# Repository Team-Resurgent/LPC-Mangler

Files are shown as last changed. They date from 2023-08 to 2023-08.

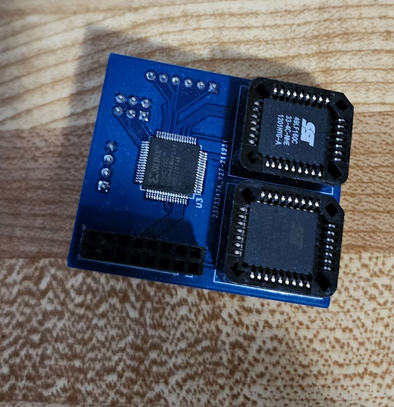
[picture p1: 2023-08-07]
Mangler2.png

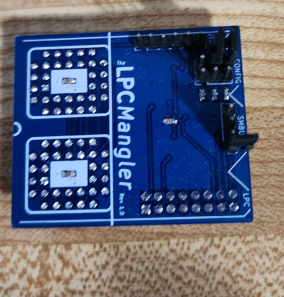
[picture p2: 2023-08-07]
Mangler1.png

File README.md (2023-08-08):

# LPC Mangler
 
A WIP/Concept Mod for original xbox. Designed by Members from Team Resurgent.
It intercepts the LPC commands between the chipset and an LPC flash chip, rewriting the command and address bits so you can use larger, later chips that don't normally reside at the same addresses as typical LPC flash chips used in simpler mods like the Aladdin , and does so while adding as few extra clock cycles as possible to the transaction

Would love for the community to contribute & complete the design

Currently supports upto 4MB Flashes. Also has ability for serial output etc.

Requires Lframe to be implemented to work with higher rev xbox possibly.

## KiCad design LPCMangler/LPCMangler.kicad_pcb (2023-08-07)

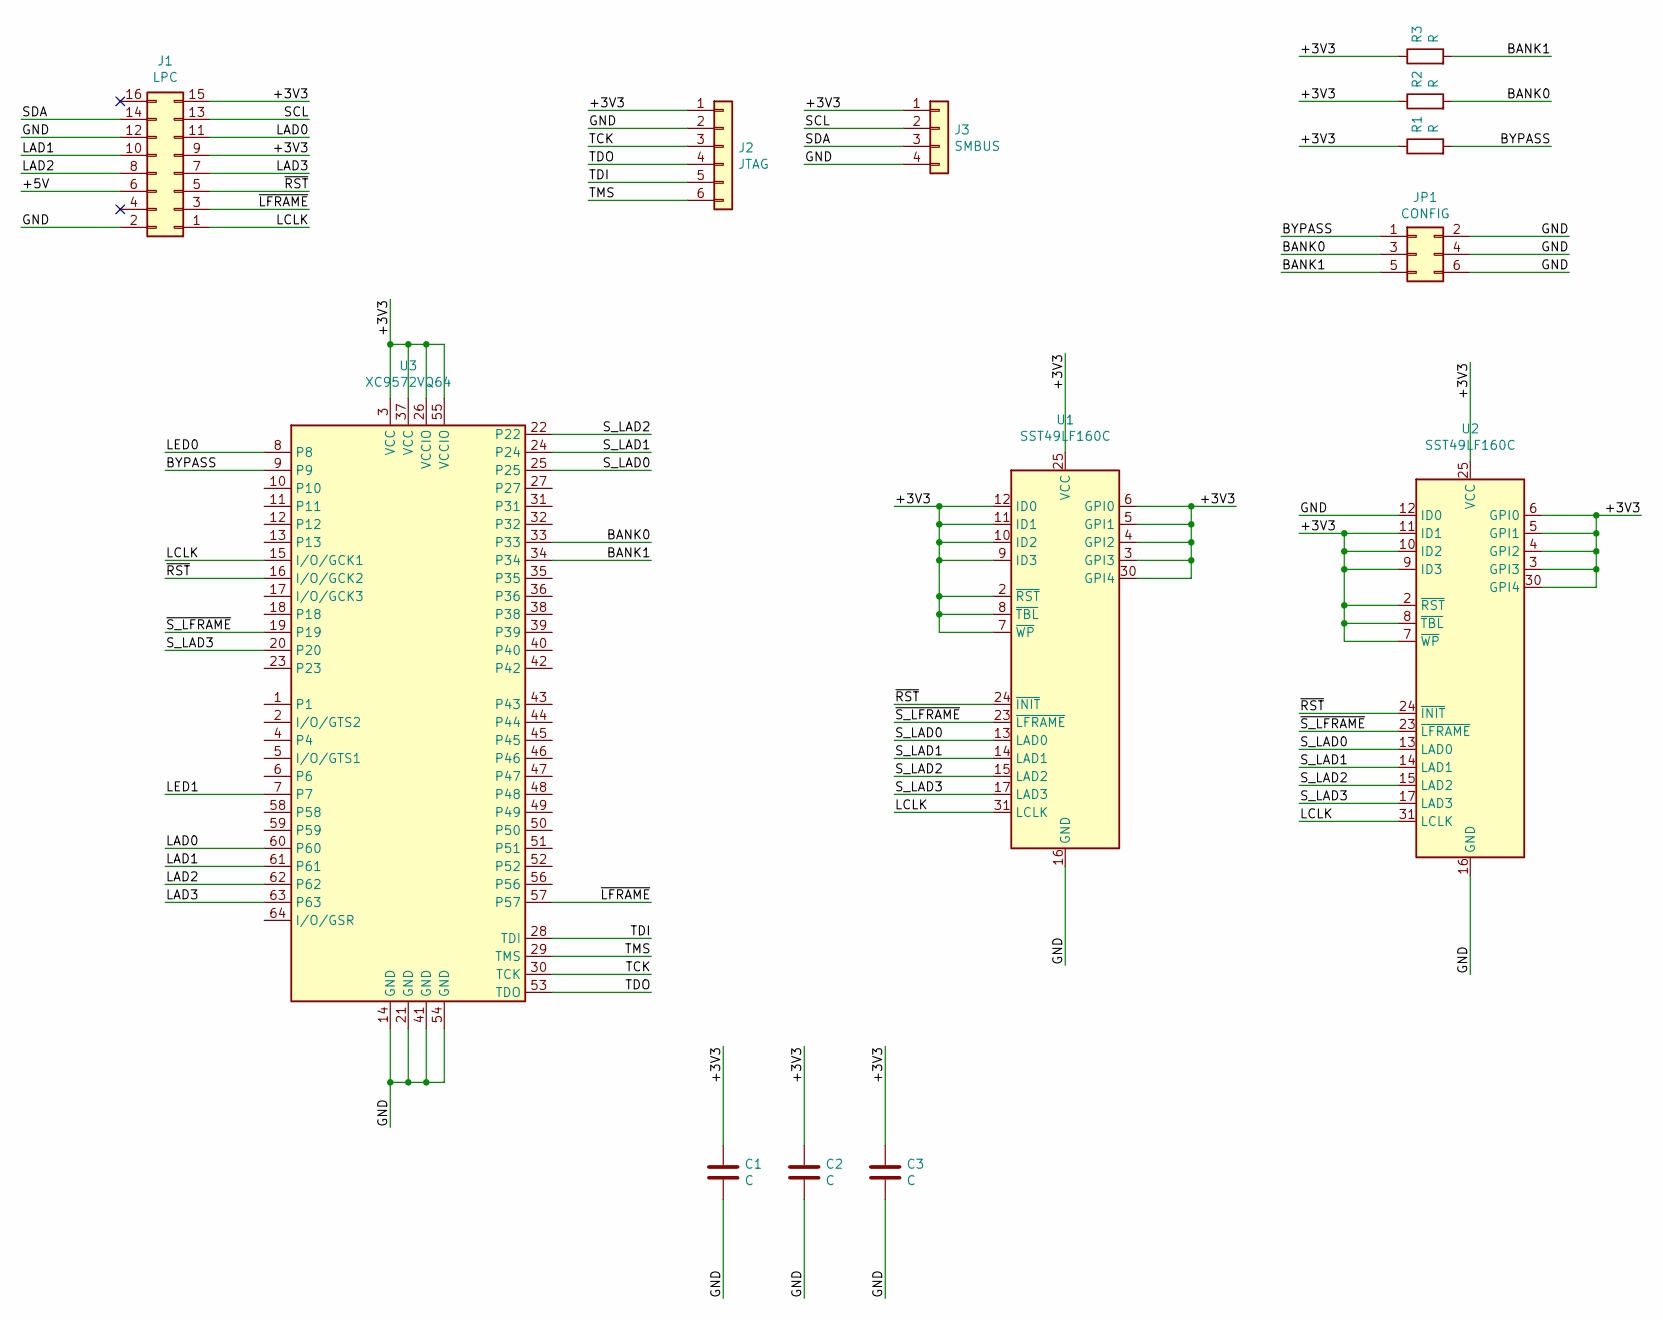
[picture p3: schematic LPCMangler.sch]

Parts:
C1, C2, C3: C; C_0603_1608Metric_Pad1.08x0.95mm_HandSolder
J1: LPC; PinSocket_2x08_P2.54mm_Vertical
J2: JTAG; PinHeader_1x06_P2.54mm_Vertical
J3: SMBUS; PinHeader_1x04_P2.54mm_Vertical
JP1: CONFIG; PinHeader_2x03_P2.54mm_Vertical
R1, R2, R3: R; R_0603_1608Metric_Pad0.98x0.95mm_HandSolder
U1, U2: SST49LF160C; PLCC-32_THT-Socket
U3: XC9572VQ64; TQFP-64_10x10mm_P0.5mm

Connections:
/+3V3: C1.1, C2.1, C3.1, J1.9, J1.15, J2.1, J3.1, R1.1, R2.1, R3.1, U1.2 (~RST), U1.3 (GPI3), U1.4 (GPI2), U1.5 (GPI1), U1.6 (GPI0), U1.7 (~WP), U1.8 (~TBL), U1.9 (ID3), U1.10 (ID2), U1.11 (ID1), U1.12 (ID0), U1.25 (VCC), U1.30 (GPI4), U2.2 (~RST), U2.3 (GPI3), U2.4 (GPI2), U2.5 (GPI1), U2.6 (GPI0), U2.7 (~WP), U2.8 (~TBL), U2.9 (ID3), U2.10 (ID2), U2.11 (ID1), U2.25 (VCC), U2.30 (GPI4), U3.3 (VCC), U3.26 (VCCIO), U3.37 (VCC), U3.55 (VCCIO)
/+5V: J1.6
/BANK0: JP1.3, R2.2, U3.33
/BANK1: JP1.5, R3.2, U3.34
/BYPASS: JP1.1, R1.2, U3.9
/GND: C1.2, C2.2, C3.2, J1.2, J1.12, J2.2, J3.4, JP1.2, JP1.4, JP1.6, U1.16 (GND), U2.12 (ID0), U2.16 (GND), U3.14 (GND), U3.21 (GND), U3.41 (GND), U3.54 (GND)
/LAD0: J1.11, U3.60
/LAD1: J1.10, U3.61
/LAD2: J1.8, U3.62
/LAD3: J1.7, U3.63
/LCLK: J1.1, U1.31 (LCLK), U2.31 (LCLK), U3.15 (I/O/GCK1)
/LED0: U3.8
/LED1: U3.7
/SCL: J1.13, J3.2
/SDA: J1.14, J3.3
/S_LAD0: U1.13 (LAD0), U2.13 (LAD0), U3.25
/S_LAD1: U1.14 (LAD1), U2.14 (LAD1), U3.24
/S_LAD2: U1.15 (LAD2), U2.15 (LAD2), U3.22
/S_LAD3: U1.17 (LAD3), U2.17 (LAD3), U3.20
/TCK: J2.3, U3.30 (TCK)
/TDI: J2.5, U3.28 (TDI)
/TDO: J2.4, U3.53 (TDO)
/TMS: J2.6, U3.29 (TMS)
/~LFRAME: J1.3, U3.57
/~RST: J1.5, U1.24 (~INIT), U2.24 (~INIT), U3.16 (I/O/GCK2)
/~S_LFRAME: U1.23 (~LFRAME), U2.23 (~LFRAME), U3.19

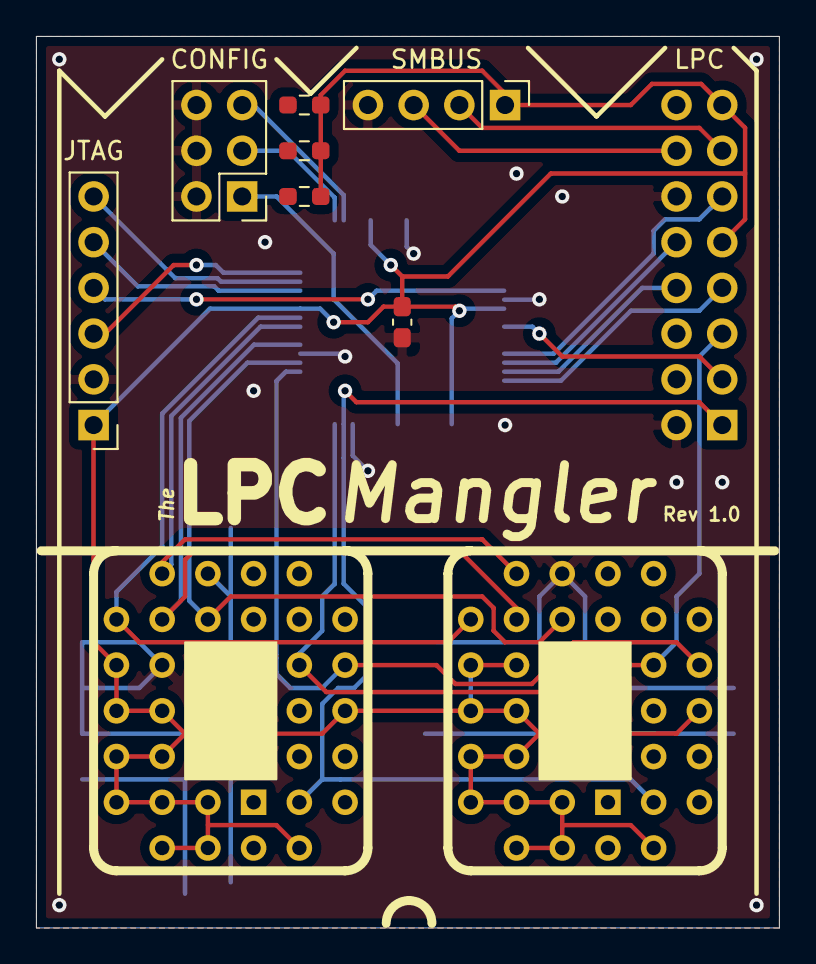
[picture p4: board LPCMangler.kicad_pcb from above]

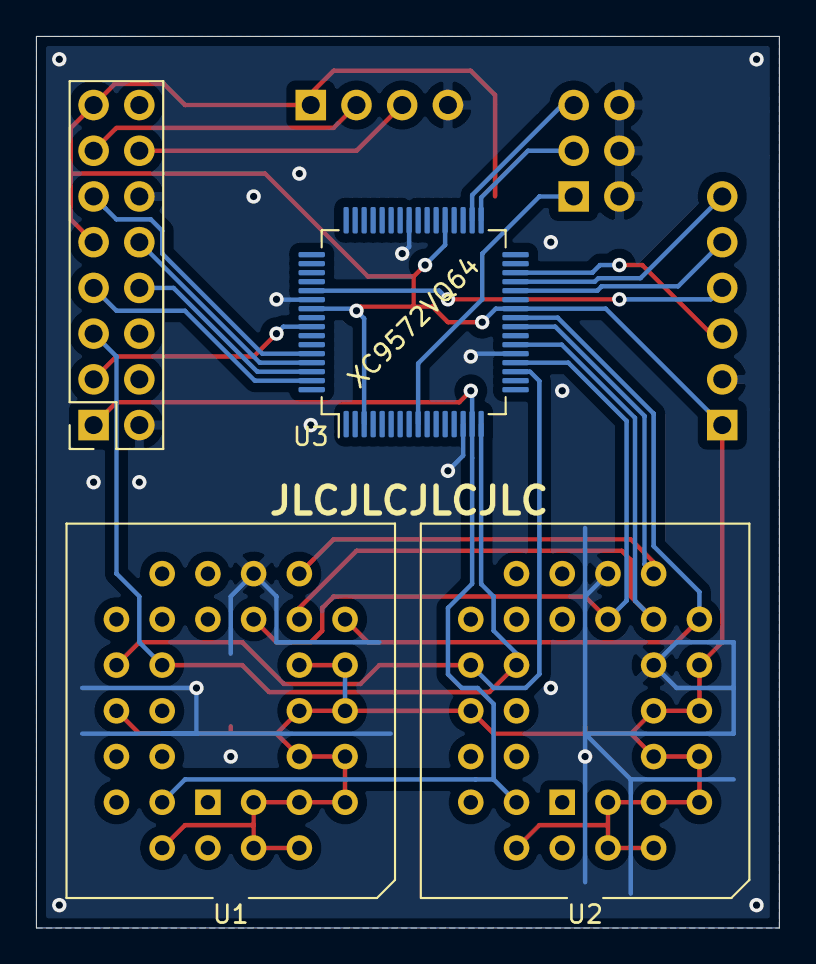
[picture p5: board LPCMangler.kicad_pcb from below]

Board: 2 copper layers, 41.3 x 49.5 mm, 13 parts (4 on the bottom side), 23 nets.
